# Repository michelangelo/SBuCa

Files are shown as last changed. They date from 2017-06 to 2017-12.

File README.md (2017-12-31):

# SBuCa

### Overview
**SBuCa** stands for Smart Business card and it's a card-sized, e-ink based, embedded platform.

### Goals of the project

Its high-level goal is to provide a reference platform for e-ink based display applications and there's nothing better than a business card for that!

Other than that, these are the main goals:

* Completely open source
* Vertical: everything has to be done in house
* Easy to carry along (it's a business card)
* Energy efficient: it's powered by two CR-2032

Everything in **SBuCa is open source**, starting with its hardware design: schematics and layout are provided along with the whole KiCad project, including eventual custom footprints.

### Cumae: SBuCa's proto-OS/firmware
As already pointed out, one of the non-functional goals of SBuCa, since its inception, was to come up with something vertical, meaning that everything had to be done from scratch, even its OS/firmware.

This goal has been achieved by **Cumae**, the proto-OS SBuCa is currently running.

Cumae, like everything else here, is totally open source and can be found on [its own repository](https://github.com/michelangelo/Cumae).

### How does it look like?

Well, it's a *business* card and it looks like this:

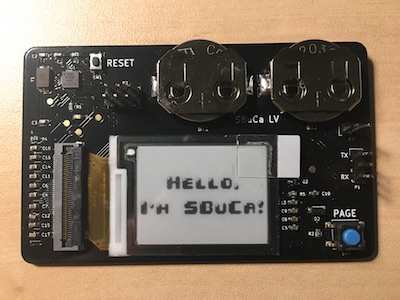
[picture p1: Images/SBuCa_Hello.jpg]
The "Hello" frame in SBuCa


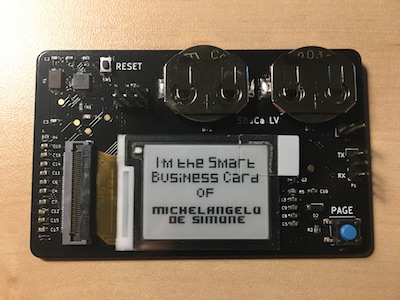
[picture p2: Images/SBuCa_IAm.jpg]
Owner presentation frame


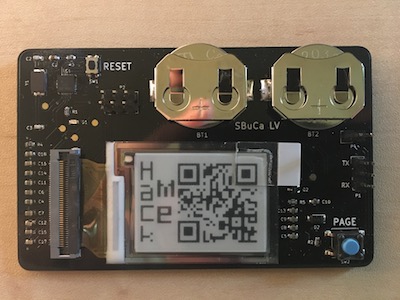
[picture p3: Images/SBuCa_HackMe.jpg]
Screensaver/HackMe Frame


### BOM

*WIP*

### Other revisions

This repository starts tracking from the LV (*Line Verification*) revision; previous revisions (B0, B1 aka "the wingboard") are not available just yet on this repository.
If you really need them just shoot the author an email.

### Author

The original author is *Michelangelo De Simone*, a system software engineer that is always open to thinker and hack around with the ultimate goal of *learning stuff, breaking things: it's the family business*. ;-)

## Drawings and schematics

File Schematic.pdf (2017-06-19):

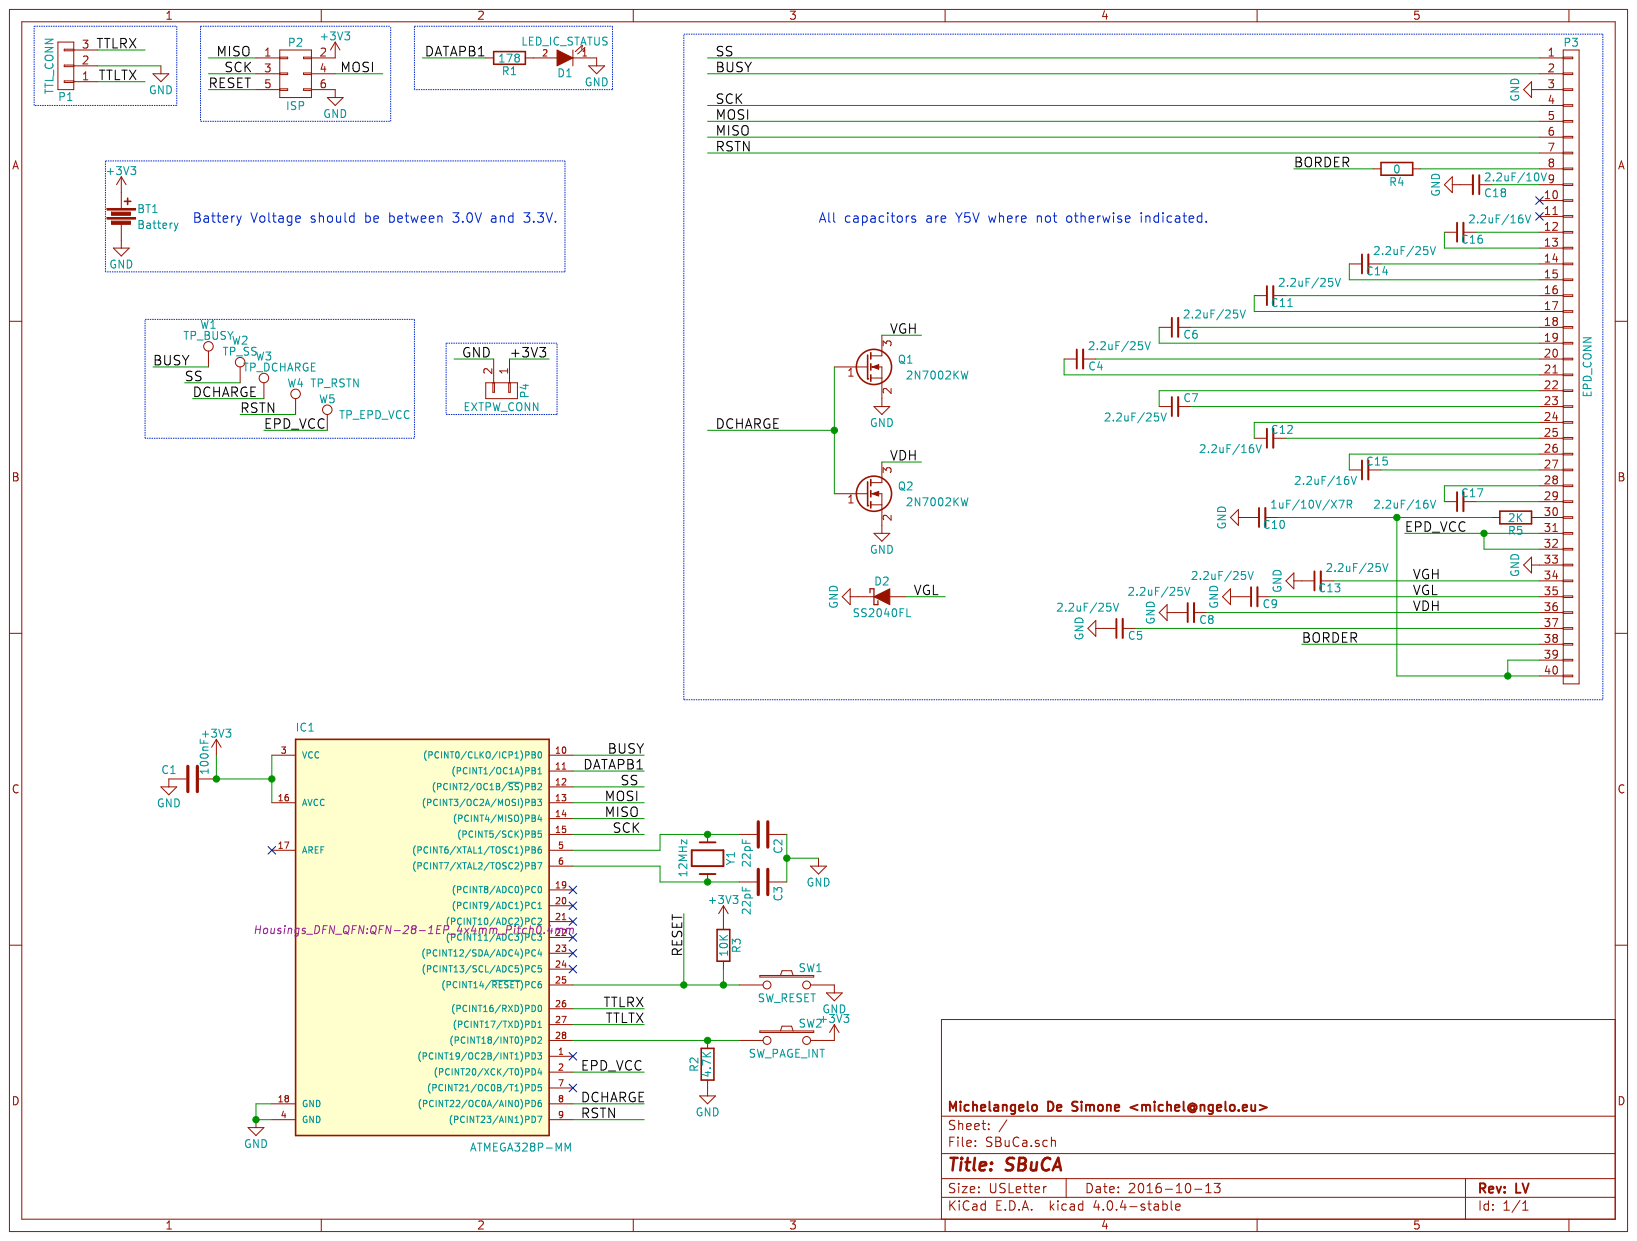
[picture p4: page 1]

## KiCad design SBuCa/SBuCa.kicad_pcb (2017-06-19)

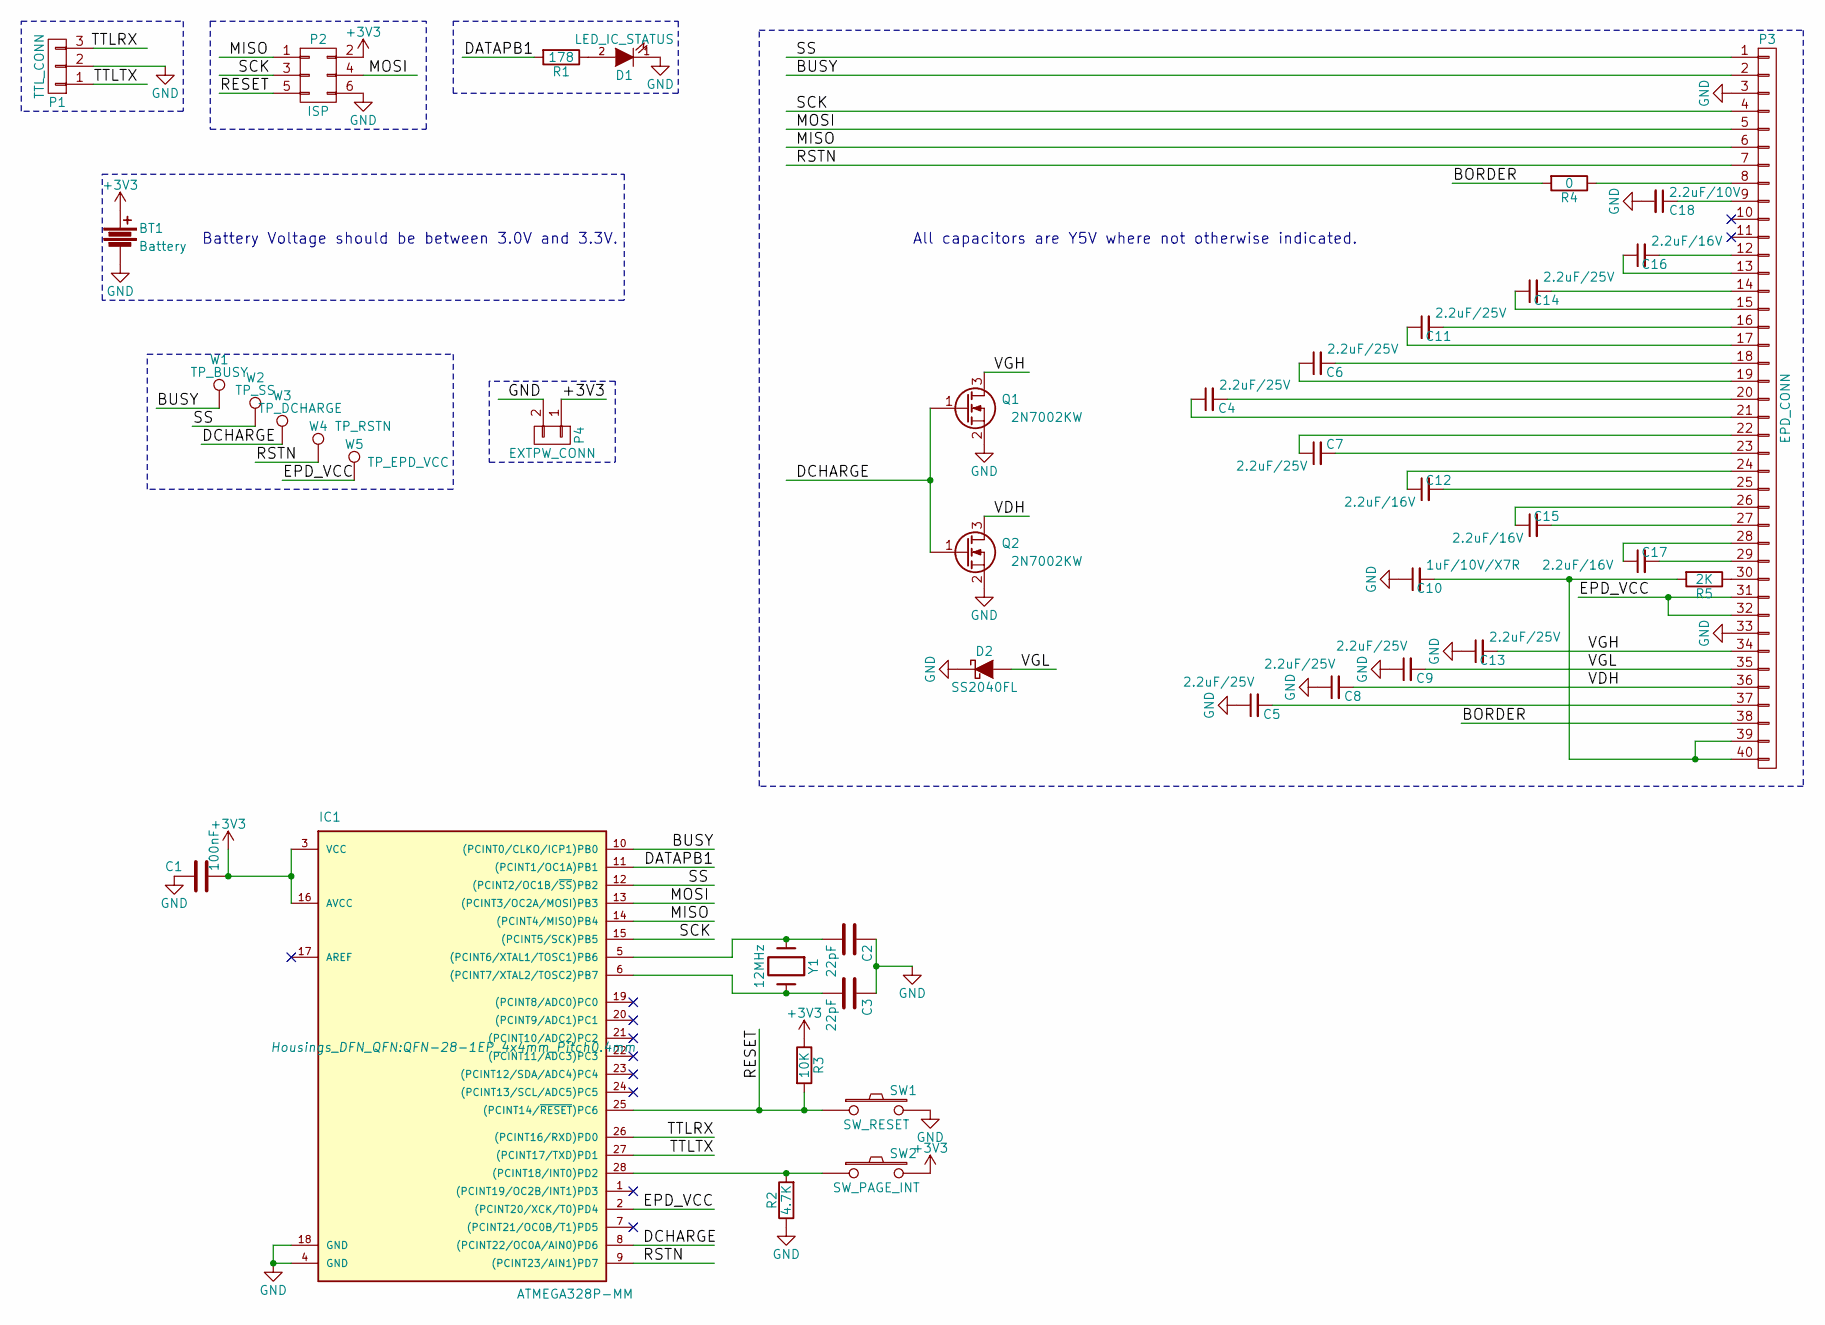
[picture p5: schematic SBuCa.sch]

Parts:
BT1: Battery; SBuCa_CR2032_Holder
C1: 100nF; C_0603
C2, C3: 22pF; C_0603
C4, C5, C6, C7, C8, C9, C11, C13, C14: 2.2uF/25V; C_0603
C10: 1uF/10V/X7R; C_0603
C12, C15, C16, C17: 2.2uF/16V; C_0603
C18: 2.2uF/10V; C_0603
D1: LED_IC_STATUS; LED_0603
D2: SS2040FL; SOD-123
IC1: ATMEGA328P-MM; QFN-28-1EP_4x4mm_Pitch0.4mm
P1: TTL_CONN; Pin_Header_Straight_1x03
P2: ISP; Pin_Header_Straight_2x03
P3: EPD_CONN; SBuCa_FH28_40_05mmpitch
P4: EXTPW_CONN; Pin_Header_Straight_1x02_Pitch2.54mm
Q1, Q2: 2N7002KW; SOT-323
R1: 178; R_0603
R2: 4.7K; R_0603
R3: 10K; R_0603
R4: 0; R_0603
R5: 2K; R_0603
SW1: SW_RESET; SW_SPST_KMR2
SW2: SW_PAGE_INT; SW_SPST_B3S-1000
W1: TP_BUSY; Measurement_Point_Round-SMD-Pad_Small
W2: TP_SS; Measurement_Point_Round-SMD-Pad_Small
W3: TP_DCHARGE; Measurement_Point_Round-SMD-Pad_Small
W4: TP_RSTN; Measurement_Point_Round-SMD-Pad_Small
W5: TP_EPD_VCC; Measurement_Point_Round-SMD-Pad_Small
Y1: 12MHz; Crystal_SMD_5032_2Pads

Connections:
+3V3: BT1.1, C1.2, IC1.3 (VCC), IC1.16 (AVCC), P2.2, P4.1, R3.1, SW2.2; also elsewhere on the board
/BORDER: P3.38, R4.2
/BUSY: IC1.10 ((PCINT0/CLKO/ICP1)PB0), P3.2, W1.1
/DATAPB1: IC1.11 ((PCINT1/OC1A)PB1), R1.2
/DCHARGE: IC1.8 ((PCINT22/OC0A/AIN0)PD6), Q1.1 (G), Q2.1 (G), W3.1
/EPD_VCC: IC1.2 ((PCINT20/XCK/T0)PD4), P3.31, P3.32, W5.1
/MISO: IC1.14 ((PCINT4/MISO)PB4), P2.1, P3.6
/MOSI: IC1.13 ((PCINT3/OC2A/MOSI)PB3), P2.4, P3.5
/RESET: IC1.25 ((PCINT14/~RESET~)PC6), P2.5, R3.2, SW1.1
/RSTN: IC1.9 ((PCINT23/AIN1)PD7), P3.7, W4.1
/SCK: IC1.15 ((PCINT5/SCK)PB5), P2.3, P3.4
/SS: IC1.12 ((PCINT2/OC1B/~SS~)PB2), P3.1, W2.1
/TTLRX: IC1.26 ((PCINT16/RXD)PD0), P1.3
/TTLTX: IC1.27 ((PCINT17/TXD)PD1), P1.1
/VDH: C8.2, P3.36, Q2.3 (D)
/VGH: C13.2, P3.34, Q1.3 (D)
/VGL: C9.2, D2.2 (A), P3.35
GND: BT1.2, C1.1, C2.1, C3.1, C5.1, C8.1, C9.1, C10.1, C13.1, C18.2, D1.1 (K), D2.1 (K), IC1.4 (GND), IC1.18 (GND), P1.2, P2.6, P3.3, P3.33, P4.2, Q1.2 (S), Q2.2 (S), R2.1, SW1.2; also elsewhere on the board
unnamed: C2.2, IC1.5 ((PCINT6/XTAL1/TOSC1)PB6), Y1.1
unnamed: C3.2, IC1.6 ((PCINT7/XTAL2/TOSC2)PB7), Y1.2
unnamed: C4.1, P3.21
unnamed: C4.2, P3.20
unnamed: C5.2, P3.37
unnamed: C6.1, P3.19
unnamed: C6.2, P3.18
unnamed: C7.1, P3.22
unnamed: C7.2, P3.23
unnamed: C10.2, P3.39, P3.40, R5.2
unnamed: C11.1, P3.17
unnamed: C11.2, P3.16
unnamed: C12.1, P3.24
unnamed: C12.2, P3.25
unnamed: C14.1, P3.15
unnamed: C14.2, P3.14
unnamed: C15.1, P3.26
unnamed: C15.2, P3.27
unnamed: C16.1, P3.13
unnamed: C16.2, P3.12
unnamed: C17.1, P3.28
unnamed: C17.2, P3.29
unnamed: C18.1, P3.9
unnamed: D1.2 (A), R1.1
unnamed: IC1.28 ((PCINT18/INT0)PD2), R2.2, SW2.1
unnamed: P3.8, R4.1
unnamed: P3.30, R5.1

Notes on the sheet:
All capacitors are Y5V where not otherwise indicated.
Battery Voltage should be between 3.0V and 3.3V.

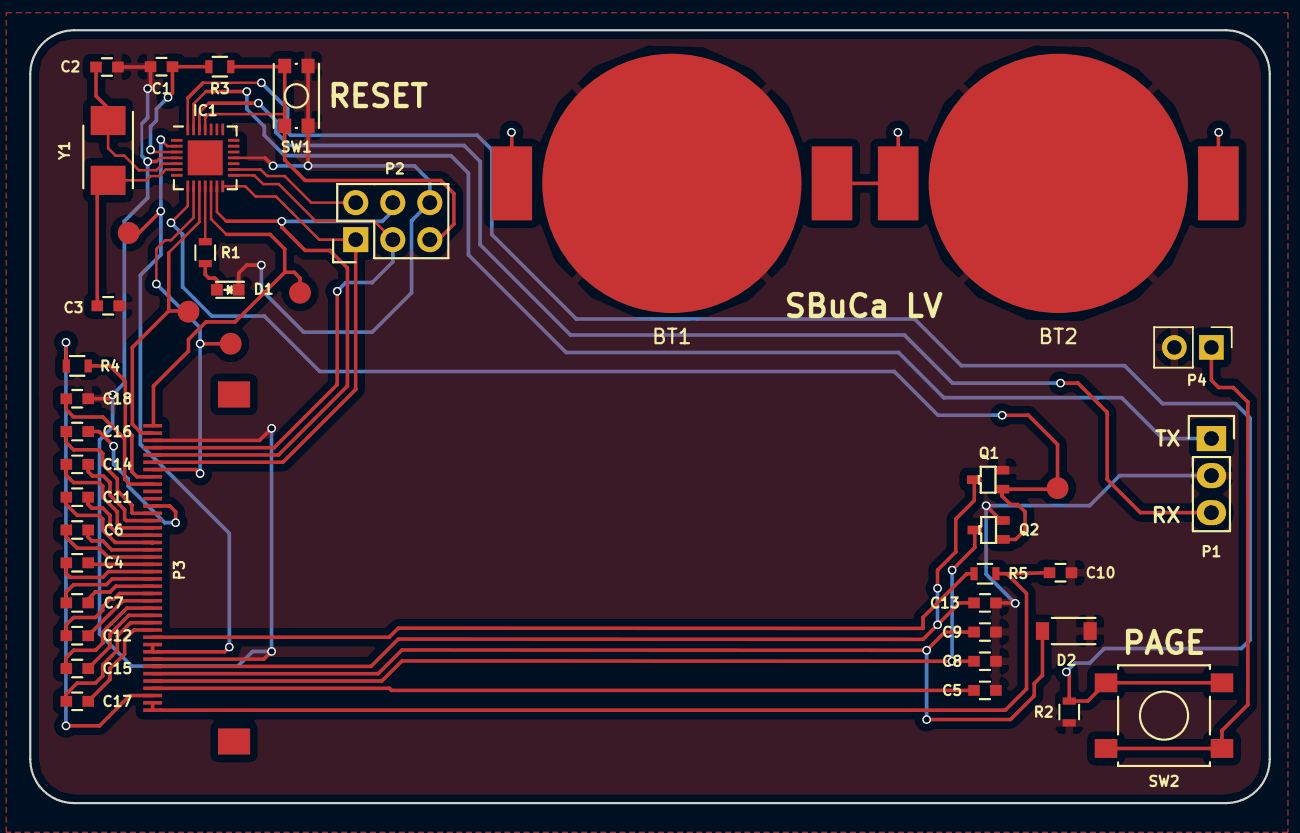
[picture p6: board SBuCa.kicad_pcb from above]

Board: 2 copper layers, 85.0 x 53.0 mm, 42 parts (0 on the bottom side), 45 nets.

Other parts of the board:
BT2: Battery; SBuCa_CR2032_Holder

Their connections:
+3V3: BT2.1; also elsewhere on the board
GND: BT2.2; also elsewhere on the board
